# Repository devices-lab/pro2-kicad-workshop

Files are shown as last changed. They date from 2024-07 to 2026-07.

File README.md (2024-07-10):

# PCB design walkthrough with KiCad workshop

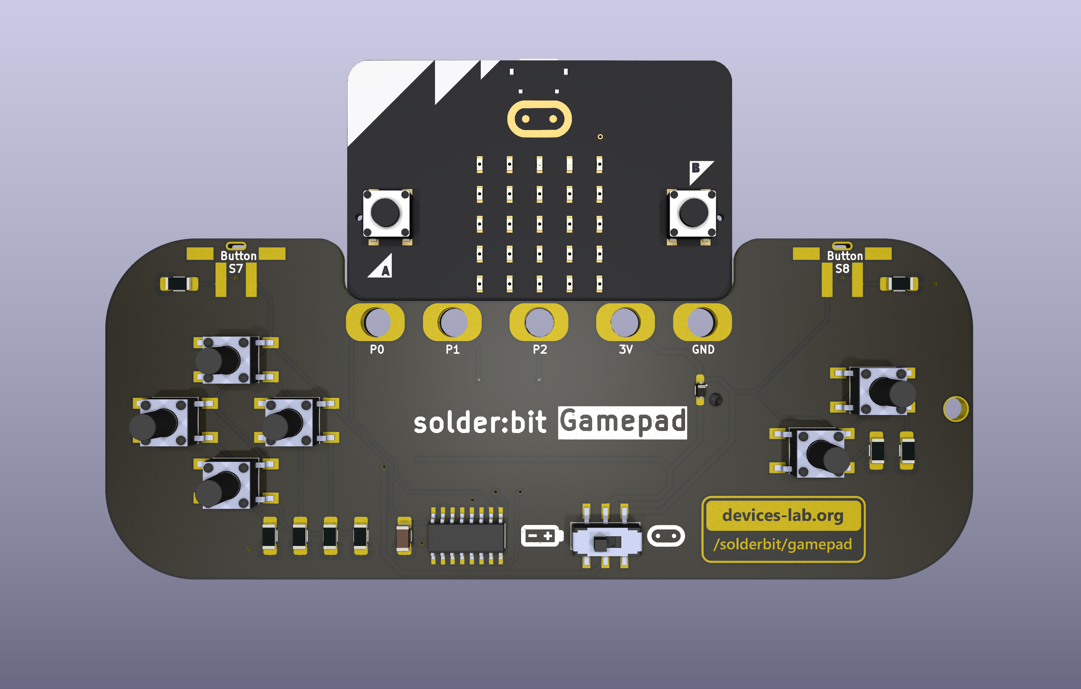
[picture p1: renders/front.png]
Front render of the solder:bit Gamepad PCB A render of the solder:bit Gamepad version of the board


## Tasks

You are given the task of extending the solder:bit Gamepad boards with more NeoPixels. A design review has highlighted that we need more blinking lights than the 5x5 LED matrix on the micro:bit can supply!

1. Download the existing design files by cloning this repository.
2. Get familiar with the NeoPixel (WS2812B) datasheet and the exisiting schematic for version 0.5.
3. Open up KiCad, and begin with the Schematic Editor - adding symbols, assiginging footprints, adding values, etc.
4. Move onto the PCB Editor and import the changes from the schematic - moving footprints, routing, zone filling, DRC, etc.
5. Build a bill of materials (BOM) and a set of Gerber fabrication files for the next workshop!
6. Use Git for version control of your KiCad project.

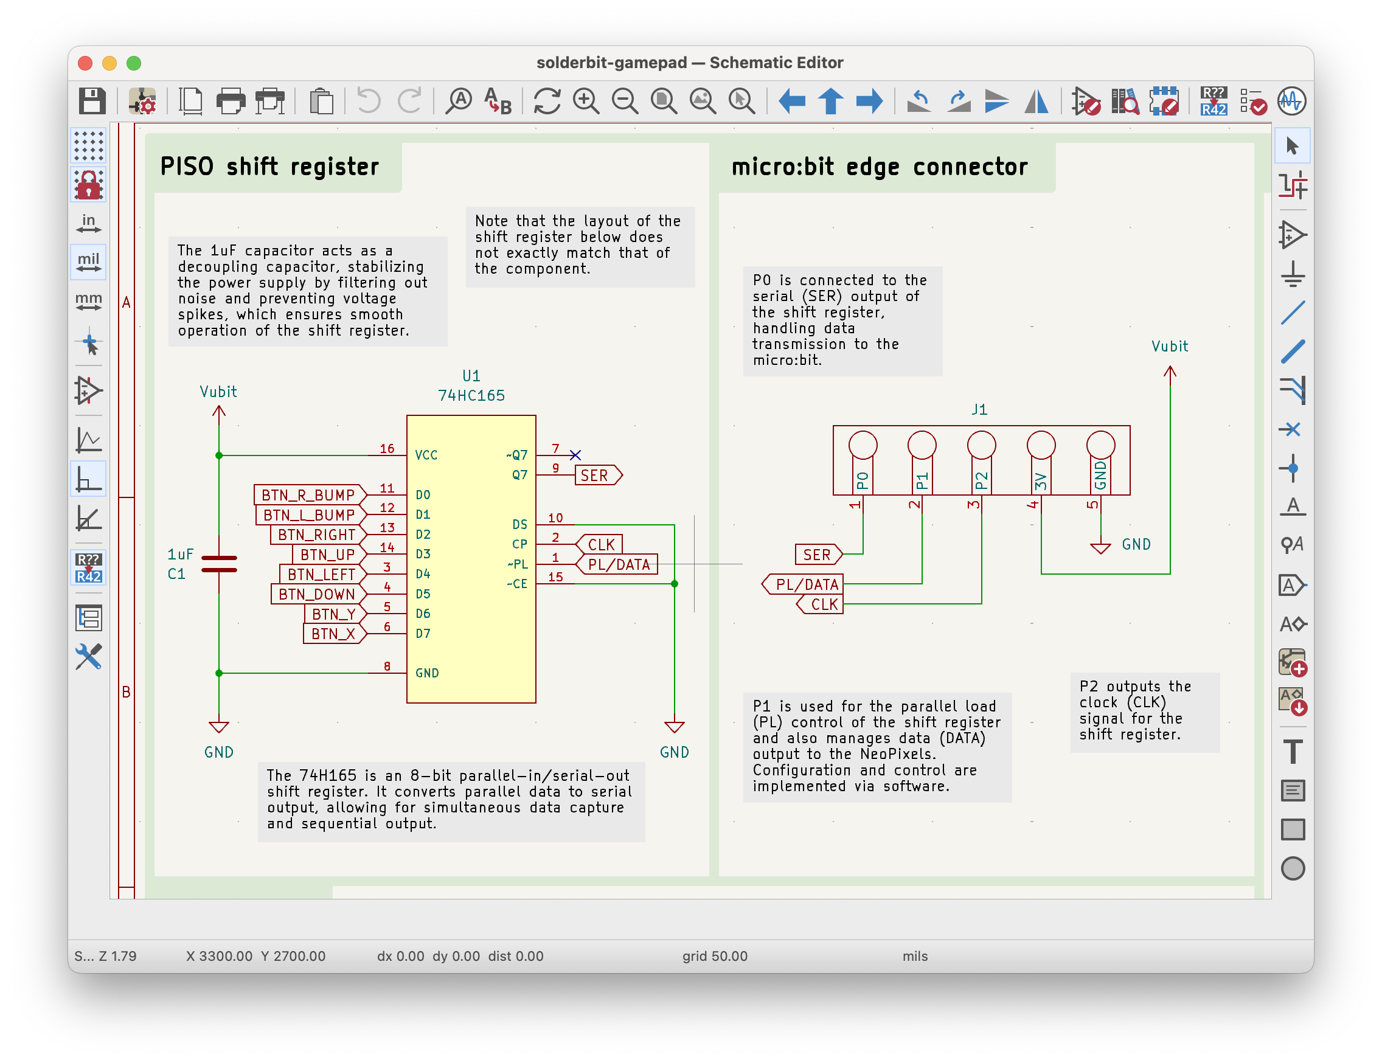
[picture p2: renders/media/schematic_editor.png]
KiCad 8.0 Schematic Editor preview

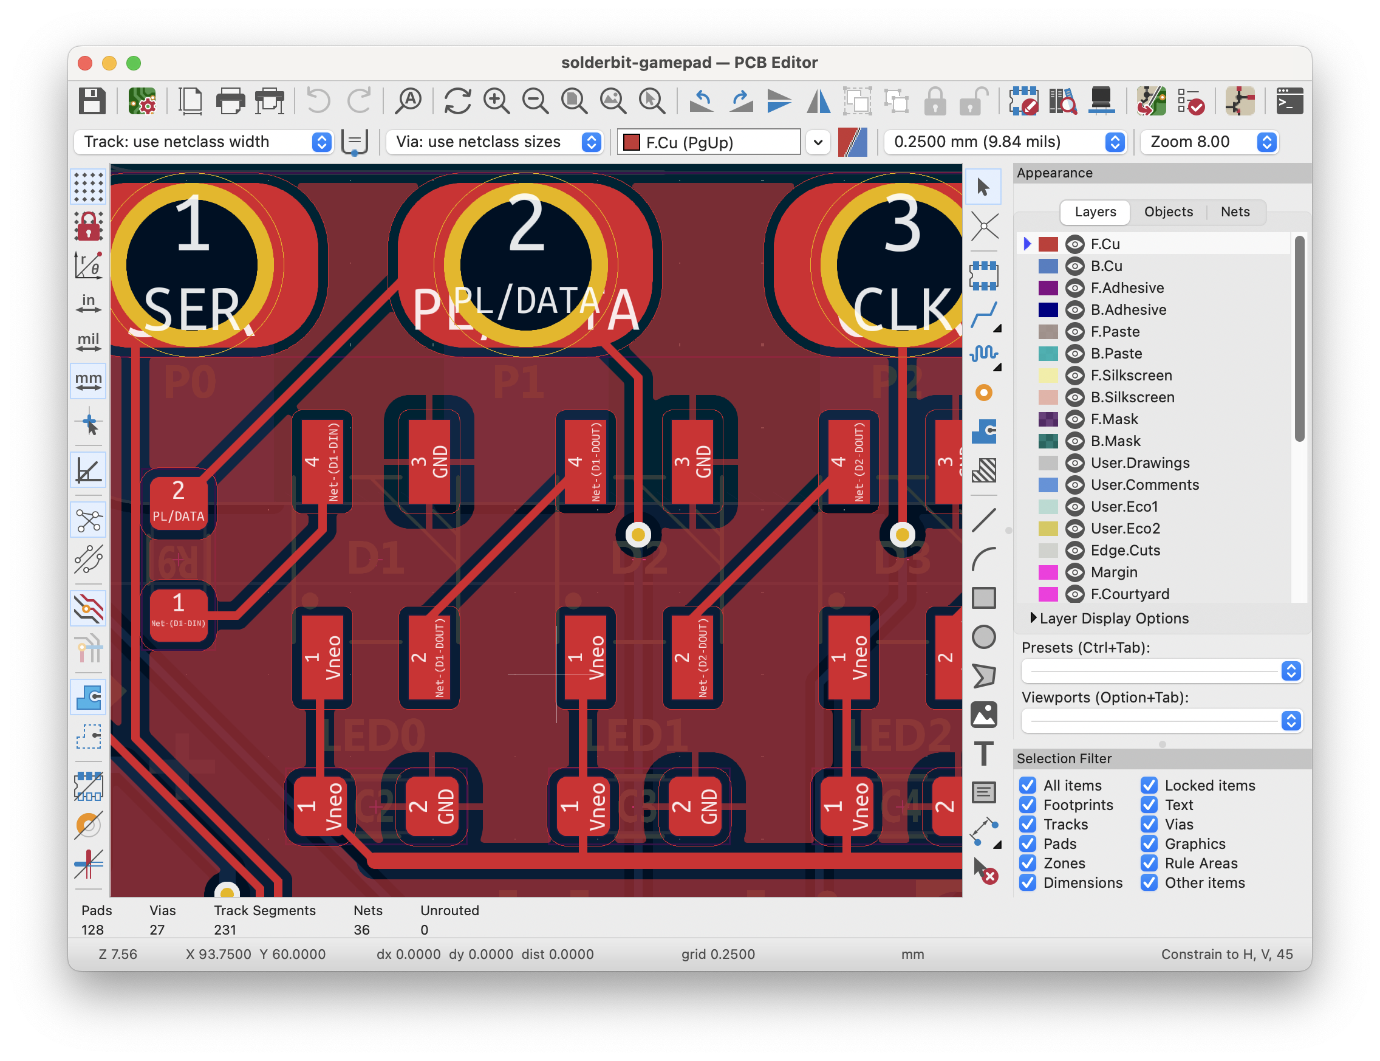
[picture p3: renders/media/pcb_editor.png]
KiCad 8.0 PCB Editor preview


Don’t worry if you don’t manage to get all the steps here completed, as we also supply a set of completed production files (BOM and Gerber files) in the same repository which can be used for the next session.

## Handy web links

- [solder:bit Gamepad repository](https://github.com/devices-lab/solderbit-gamepad)
- [KiCad 8.0 documentation](https://docs.kicad.org/8.0/en/)
- [Git cheat sheet](https://education.github.com/git-cheat-sheet-education.pdf)

## Credits

Thanks to [Dr John Vidler](https://github.com/JohnVidler) and [Aron Eggens](https://github.com/mac-aron), the Computing and Communications departement at Lancaster University, and everyone at the [Devices Lab](https://github.com/devices-lab).

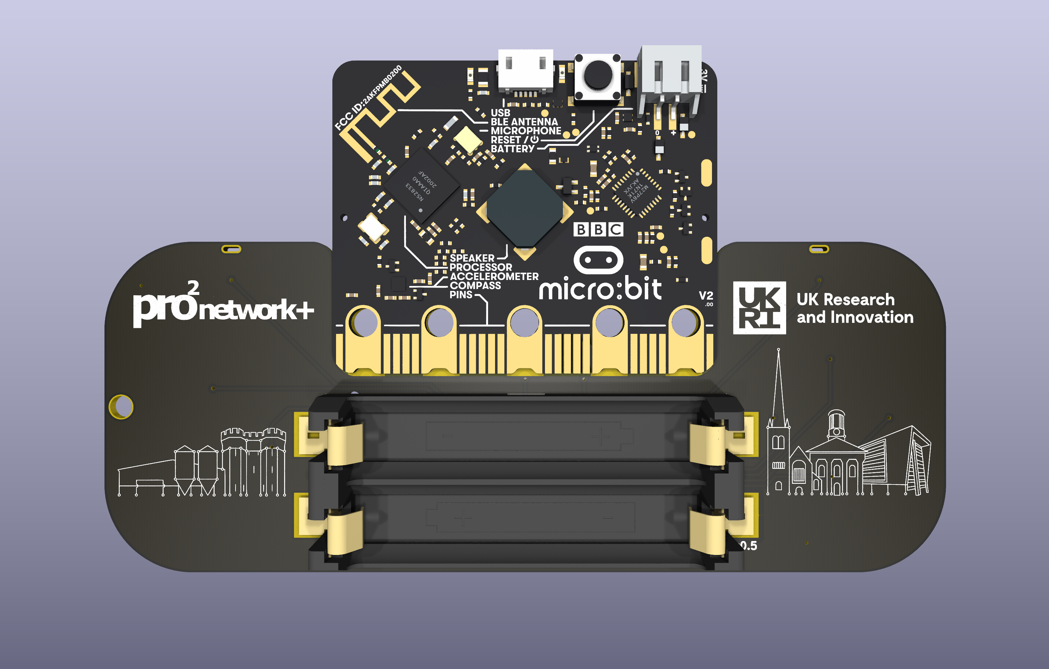
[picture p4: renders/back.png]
Rear render of the solder:bit Gamepad A render of the solder:bit Gamepad version of the board


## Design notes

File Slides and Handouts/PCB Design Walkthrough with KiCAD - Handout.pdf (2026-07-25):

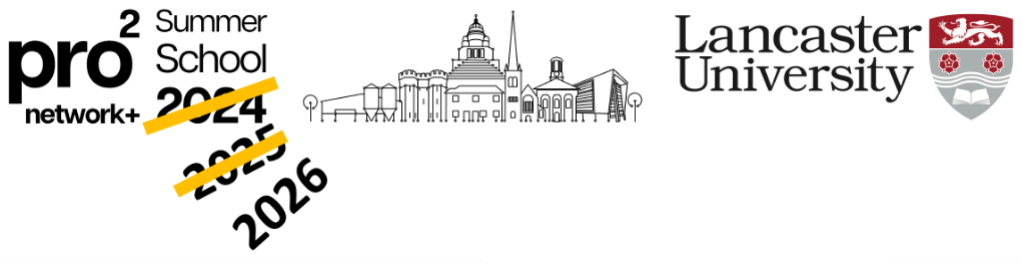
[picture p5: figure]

# PCB Design Walkthrough with KiCAD

John Vidler and Aron Eggens Computing and Communications Lancaster University

# https://tinyurl.com/kicad-class

You are given the task of extending the Solder:bit boards with more NeoPixel LEDs. A design review has highlighted that we need more blinking lights than the 5x5 LED matrix on the Micro:bit can supply!

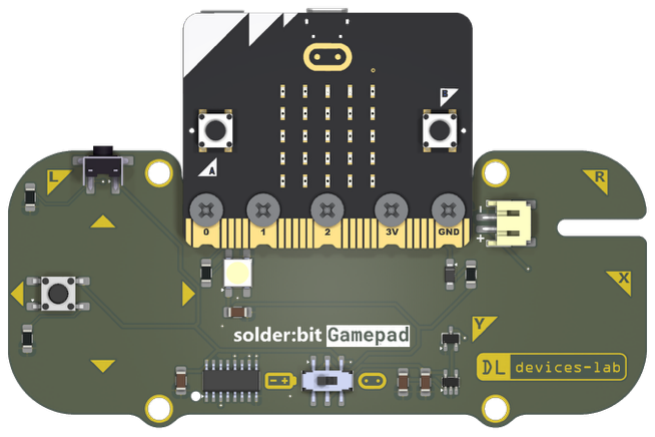
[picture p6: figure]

1. Download the existing design files by cloning or downloading the repository

https://github.com/devices-lab/pro2-kicad-workshop

( Direct Zip download: https://tinyurl.com/kicad-files )

2. Add 5 Neopixels and their support components to the design in the Schematic Editor
3. Select which footprints you need for the new parts with the Part Selection tool
4. Move to the PCB Layout Editor and import the changes
5. Lay out your new components (extra points for being artistic with your placement! 😊)
6. Build a Bill Of Materials (BOM) and Gerber file set for the next workshop

## Online KiCAD documentation https://docs.kicad.org/

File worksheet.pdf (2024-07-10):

## PCB Design Walkthrough with KiCAD

John Vidler and Aron Eggens Computing and Communications Lancaster University
https://github.com/devices-lab/pro2-kicad-workshop

You are given the task of extending the Solder:bit boards with more NeoPixel LEDs. A design review has highlighted that we need more blinking lights than the 5x5 LED matrix on the Micro:bit can supply!

## Tasks:

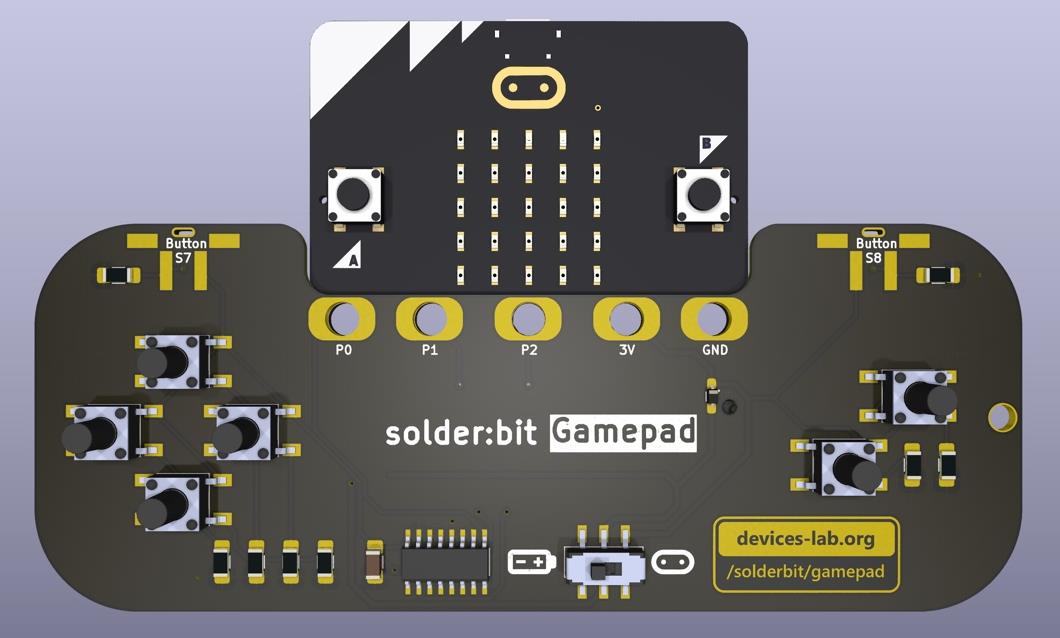
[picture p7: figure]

1. Download the existing design files by cloning the Git repository:

https://github.com/devices-lab/pro2-kicad-workshop

2. Add 5 Neopixels and their support components to the design in the Schematic Editor
3. Select which footprints you need for the new parts with the Part Selection tool
4. Move to the PCB Layout Editor and import the changes
5. Lay out your new components (extra points for being artistic with your placement! )
6. Build a Bill Of Materials (BOM) and Gerber file set for the next workshop

Don’t worry if you don’t manage to get all the steps here completed, as we also supply a set of completed production files (BOM and Gerber files) in the same repository which can be used for the next session.

## Handy Web Links:

- https://docs.kicad.org/8.0/en/ - The Version 8 KiCAD documentation
- https://education.github.com/git-cheat-sheet-education.pdf - A Git cheat sheet

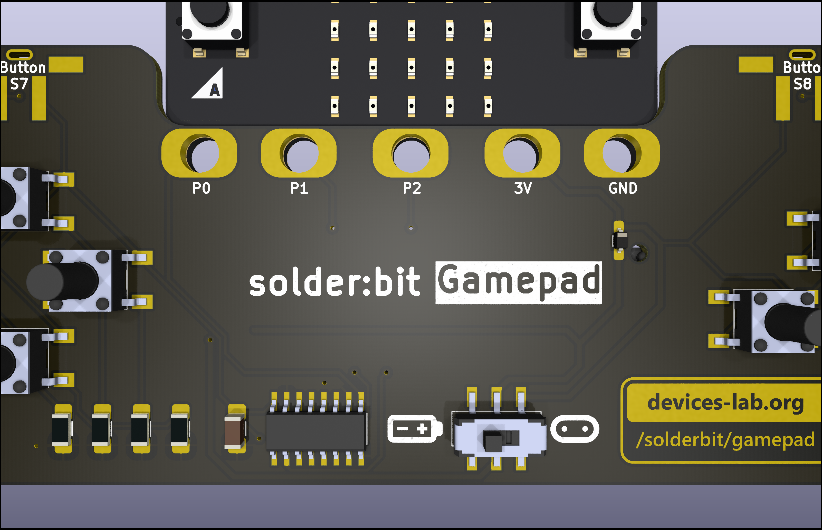
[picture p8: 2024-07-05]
renders/front-zoom.png

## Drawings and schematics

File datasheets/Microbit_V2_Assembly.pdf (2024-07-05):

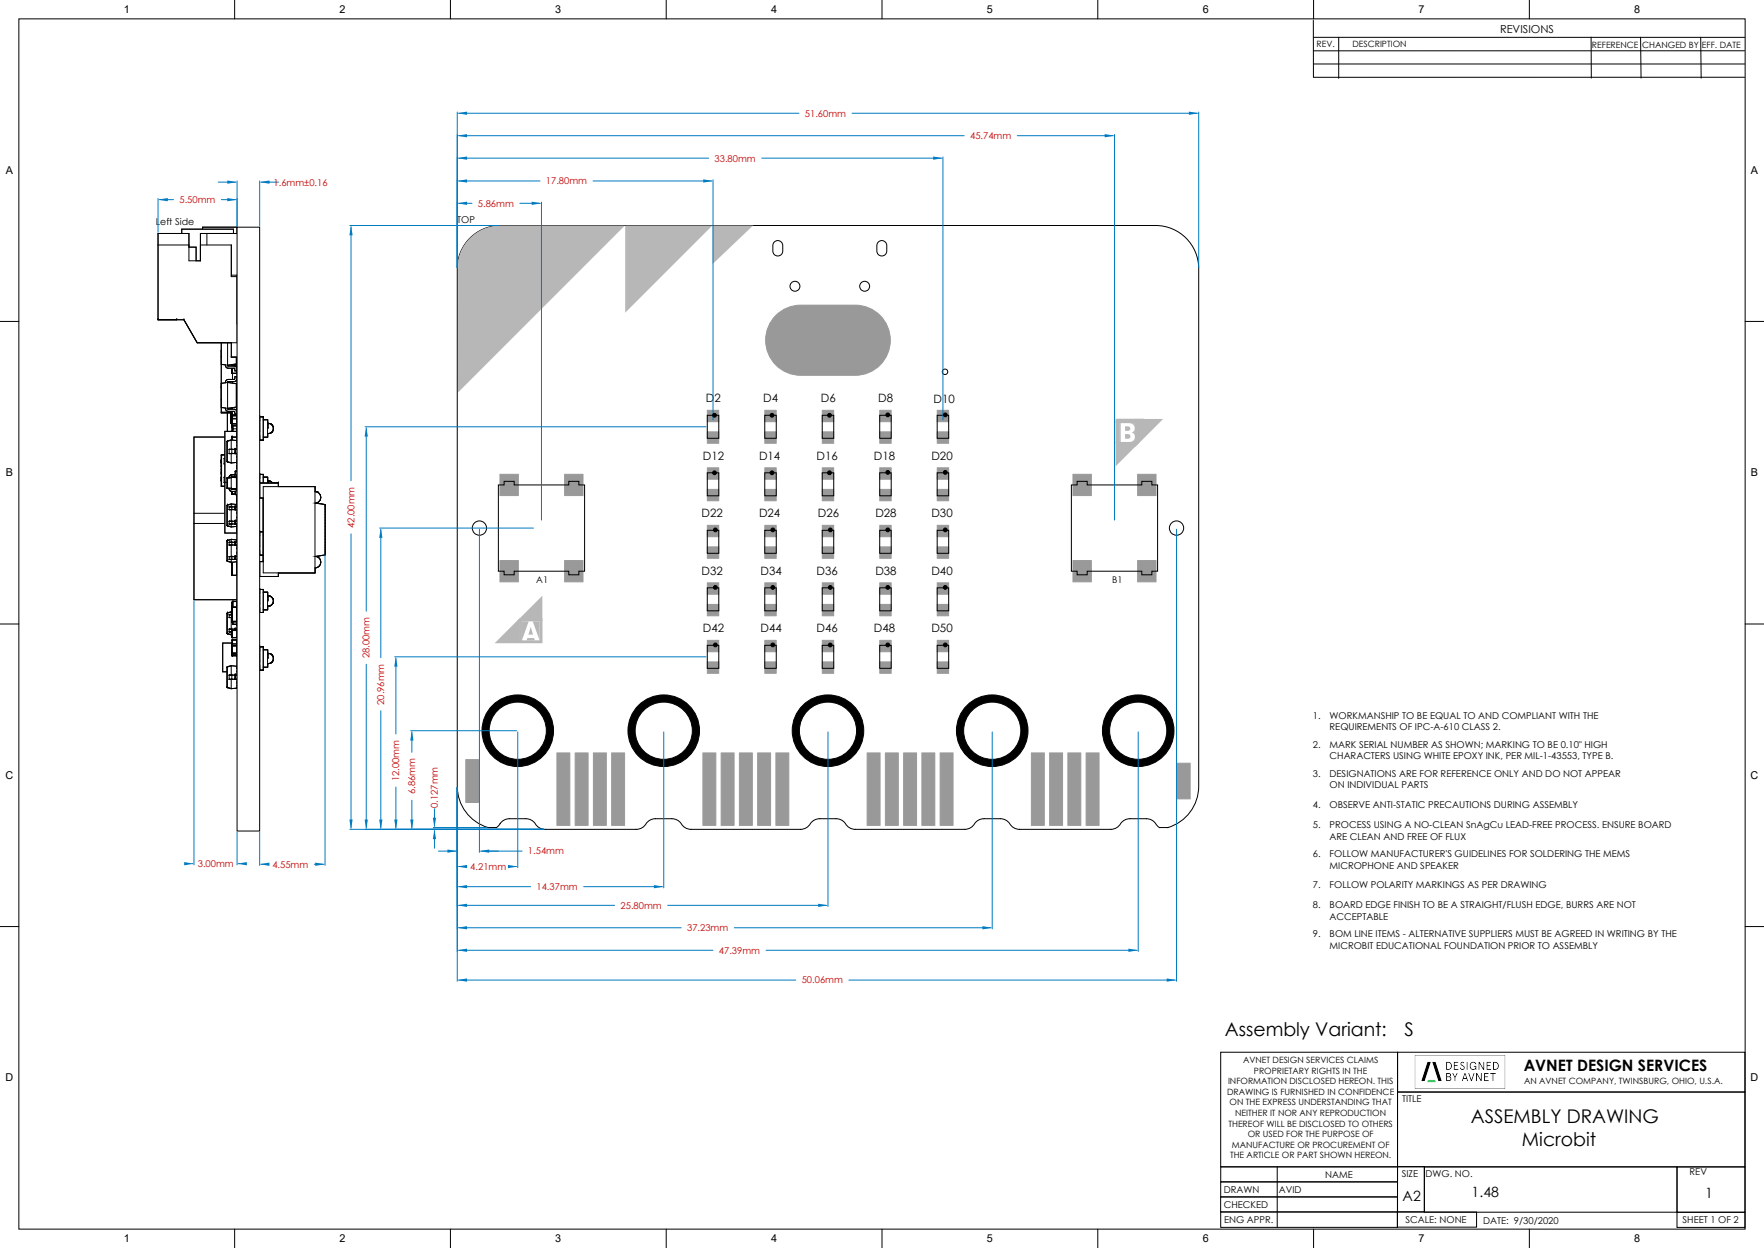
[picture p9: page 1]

WORKMANSHIP TO BE EQUAL TO AND COMPLIANT WITH THE
REQUIREMENTS OF IPC-A-610 CLASS 2.
MARK SERIAL NUMBER AS SHOWN; MARKING TO BE 0.10" HIGH
CHARACTERS USING WHITE EPOXY INK, PER MIL-1-43553, TYPE B.
DESIGNATIONS ARE FOR REFERENCE ONLY AND DO NOT APPEAR
ON INDIVIDUAL PARTS
4. OBSERVE ANTI-STATIC PRECAUTIONS DURING ASSEMBLY
PROCESS USING A NO-CLEAN SnAgCu LEAD-FREE PROCESS. ENSURE BOARD
ARE CLEAN AND FREE OF FLUX
FOLLOW MANUFACTURER'S GUIDELINES FOR SOLDERING THE MEMS
MICROPHONE AND SPEAKER
7. FOLLOW POLARITY MARKINGS AS PER DRAWING
BOARD EDGE FINISH TO BE A STRAIGHT/FLUSH EDGE, BURRS ARE NOT
ACCEPTABLE
BOM LINE ITEMS - ALTERNATIVE SUPPLIERS MUST BE AGREED IN WRITING BY THE
MICROBIT EDUCATIONAL FOUNDATION PRIOR TO ASSEMBLY

AVNET DESIGN SERVICES CLAIMS
PROPRIETARY RIGHTS IN THE
INFORMATION DISCLOSED HEREON. THIS
DRAWING IS FURNISHED IN CONFIDENCE
ON THE EXPRESS UNDERSTANDING THAT
NEITHER IT NOR ANY REPRODUCTION
THEREOF WILL BE DISCLOSED TO OTHERS
OR USED FOR THE PURPOSE OF
MANUFACTURE OR PROCUREMENT OF
THE ARTICLE OR PART SHOWN HEREON.

AVNET DESIGN SERVICES
AN AVNET COMPANY, TWINSBURG, OHIO, U.S.A.
ASSEMBLY DRAWING
Microbit

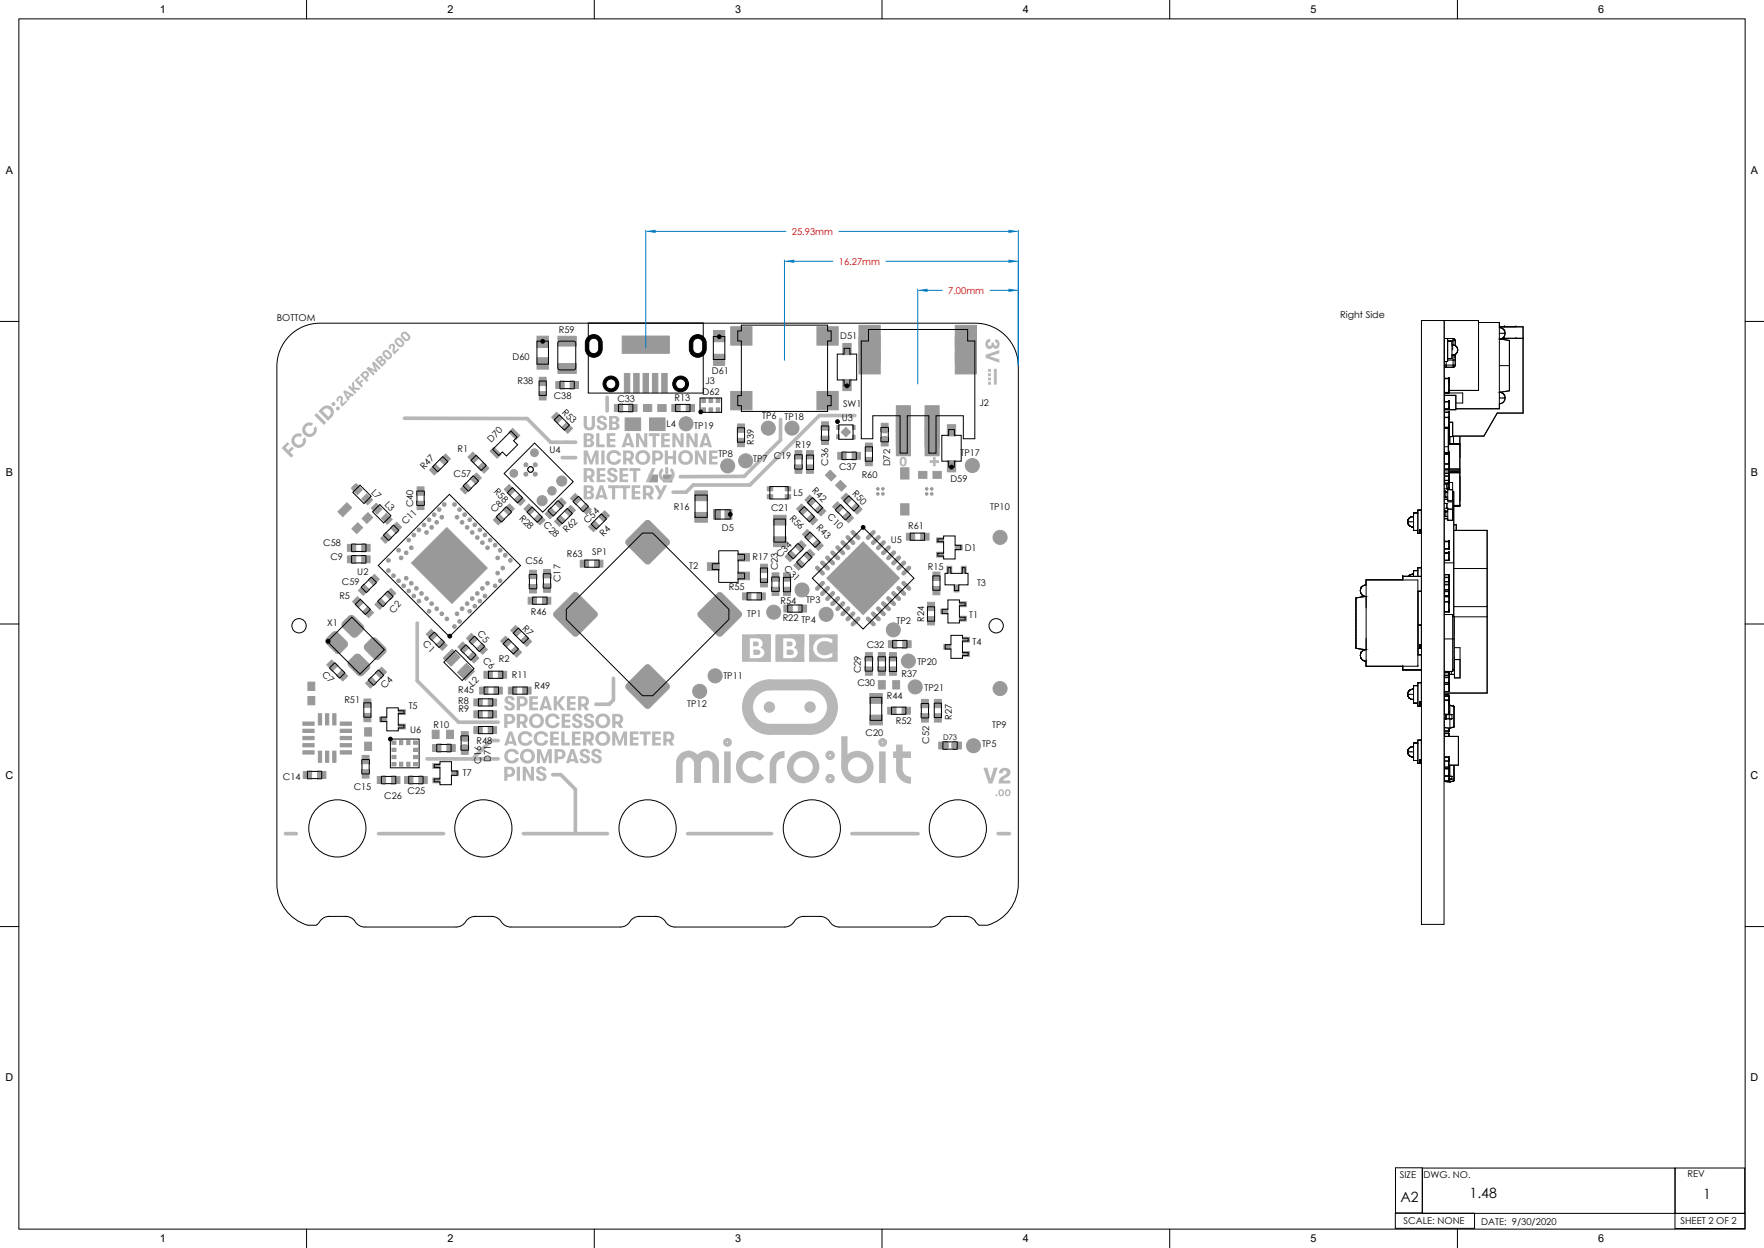
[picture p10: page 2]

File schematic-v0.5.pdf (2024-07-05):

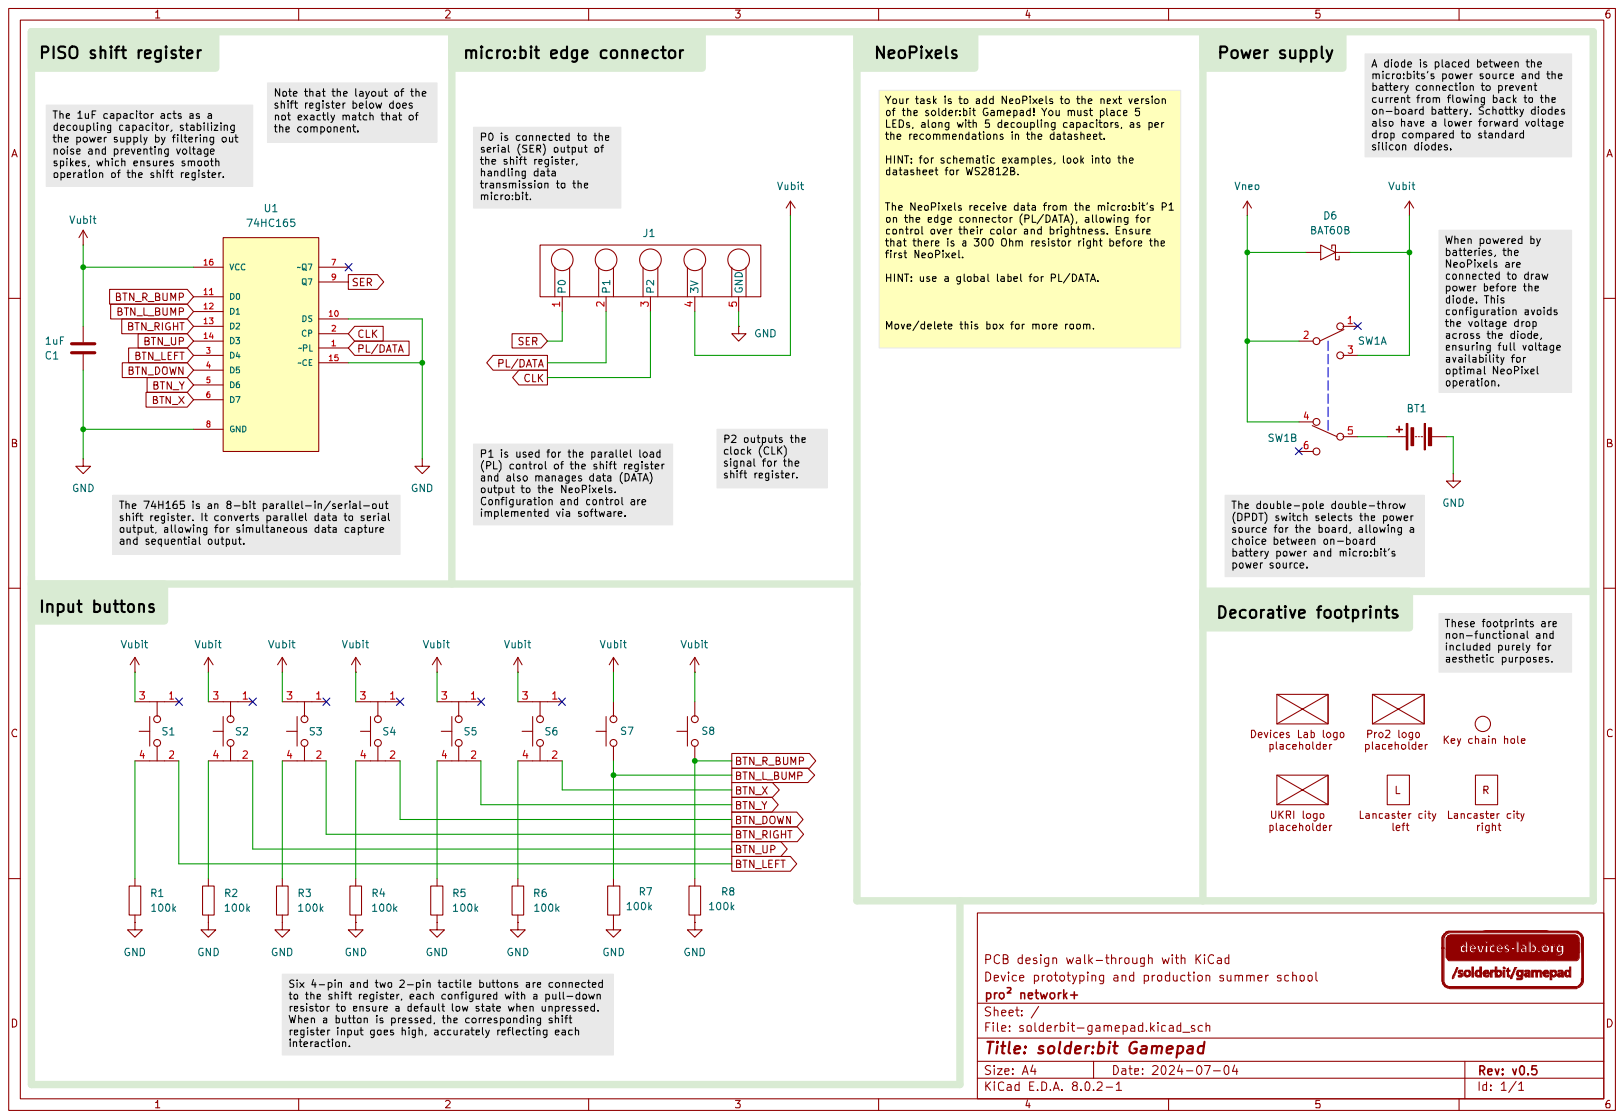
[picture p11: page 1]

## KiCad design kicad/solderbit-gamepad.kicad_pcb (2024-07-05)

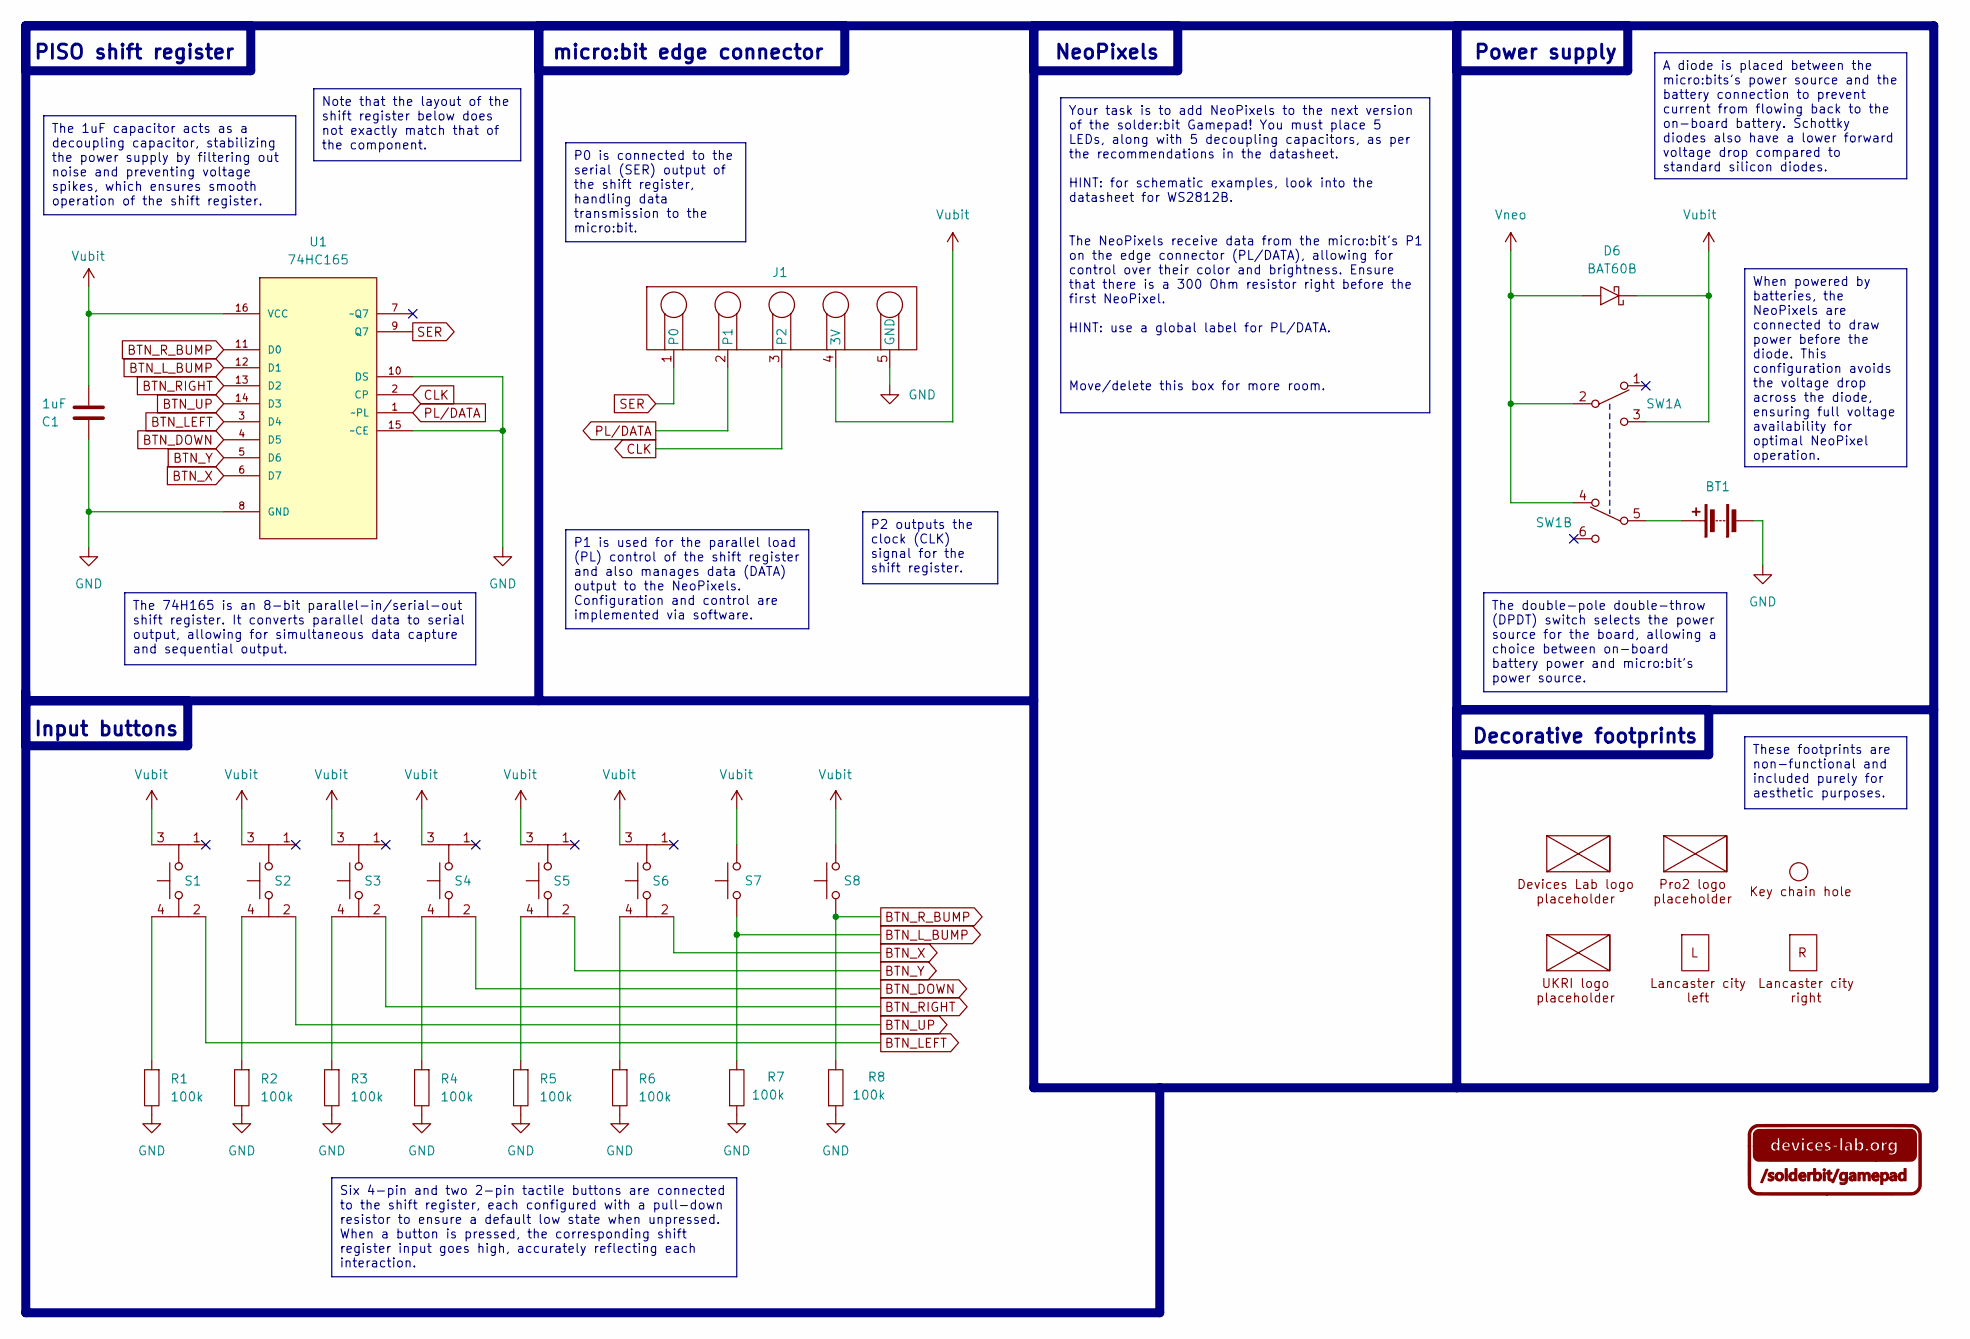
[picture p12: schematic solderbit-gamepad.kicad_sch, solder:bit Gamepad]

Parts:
BT1: BH-AAA-B5AA001; Battery_Holder
C1: 1uF; 1206_Capacitor
D6: BAT60B; Schottky_Diode_SOD-323
G1: Devices-Lab_Logo_H9mm
G2: Pro2_Logo
G3: Key_Chain_Hole
G4: UKRI_Logo
G5: LSS_L
G6: LSS_R
J1: Microbit; Microbit_Edge_Connector
R1, R2, R3, R4, R5, R6, R7, R8: 100k; 1206_Resistor
S1, S2, S3, S4, S5, S6: TS-1002S-AR06026; Tactile_Switch
S7: TS-1037-A4B3-D2; Tactile_Switch_Left_90_Degrees
S8: TS-1037-A4B3-D2; Tactile_Switch_Right_90_Degrees
SW1: MST22D18G2 125; Sliding_Switch_DPDT
U1: 74HC165; Shift_Register_74HC165D

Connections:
BTN_DOWN: S4.2, U1.4 (D5)
BTN_LEFT: S1.2, U1.3 (D4)
BTN_L_BUMP: R7.2, S7.2, U1.12 (D1)
BTN_RIGHT: S3.2, U1.13 (D2)
BTN_R_BUMP: R8.2, S8.2, U1.11 (D0)
BTN_UP: S2.2, U1.14 (D3)
BTN_X: S6.2, U1.6 (D7)
BTN_Y: S5.2, U1.5 (D6)
CLK: J1.3 (P2), U1.2 (CP)
GND: BT1.2 (-), C1.1, J1.5 (GND), R1.2, R2.2, R3.2, R4.2, R5.2, R6.2, R7.1, R8.1, U1.8 (GND), U1.10 (DS), U1.15 (~CE)
unnamed: BT1.1 (+), SW1.5 (B)
unnamed: R1.1, S1.4
unnamed: R2.1, S2.4
unnamed: R3.1, S3.4
unnamed: R4.1, S4.4
unnamed: R5.1, S5.4
unnamed: R6.1, S6.4
PL/DATA: J1.2 (P1), U1.1 (~PL)
SER: J1.1 (P0), U1.9 (Q7)
Vneo: D6.2 (A), SW1.2 (B), SW1.4 (A)
Vubit: C1.2, D6.1 (K), J1.4 (3V), S1.3, S2.3, S3.3, S4.3, S5.3, S6.3, S7.1, S8.1, SW1.3 (C), U1.16 (VCC)

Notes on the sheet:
P0 is connected to the serial (SER) output of the shift register, handling data transmission to the micro:bit.
When powered by batteries, the NeoPixels are connected to draw power before the diode. This configuration avoids the voltage drop across the diode, ensuring full voltage availability for optimal NeoPixel operation.
P2 outputs the clock (CLK) signal for the shift register.
P1 is used for the parallel load (PL) control of the shift register and also manages data (DATA) output to the NeoPixels. Configuration and control are implemented via software.
The 74H165 is an 8-bit parallel-in/serial-out shift register. It converts parallel data to serial output, allowing for simultaneous data capture and sequential output.
Your task is to add NeoPixels to the next version of the solder:bit Gamepad! You must place 5 LEDs, along with 5 decoupling capacitors, as per the recommendations in the datasheet. HINT: for schematic examples, look into the datasheet for WS2812B. The NeoPixels receive data from the micro:bit's P1 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
The double-pole double-throw (DPDT) switch selects the power source for the board, allowing a choice between on-board battery power and micro:bit's power source.
Six 4-pin and two 2-pin tactile buttons are connected to the shift register, each configured with a pull-down resistor to ensure a default low state when unpressed. When a button is pressed, the corresponding shift register input goes high, accurately reflecting each interaction.
These footprints are non-functional and included purely for aesthetic purposes.
A diode is placed between the micro:bits's power source and the battery connection to prevent current from flowing back to the on-board battery. Schottky diodes also have a lower forward voltage drop compared to standard silicon diodes.
The 1uF capacitor acts as a decoupling capacitor, stabilizing the power supply by filtering out noise and preventing voltage spikes, which ensures smooth operation of the shift register.
Note that the layout of the shift register below does not exactly match that of the component.
NeoPixels
Input buttons
Power supply
micro:bit edge connector
Decorative footprints
PISO shift register

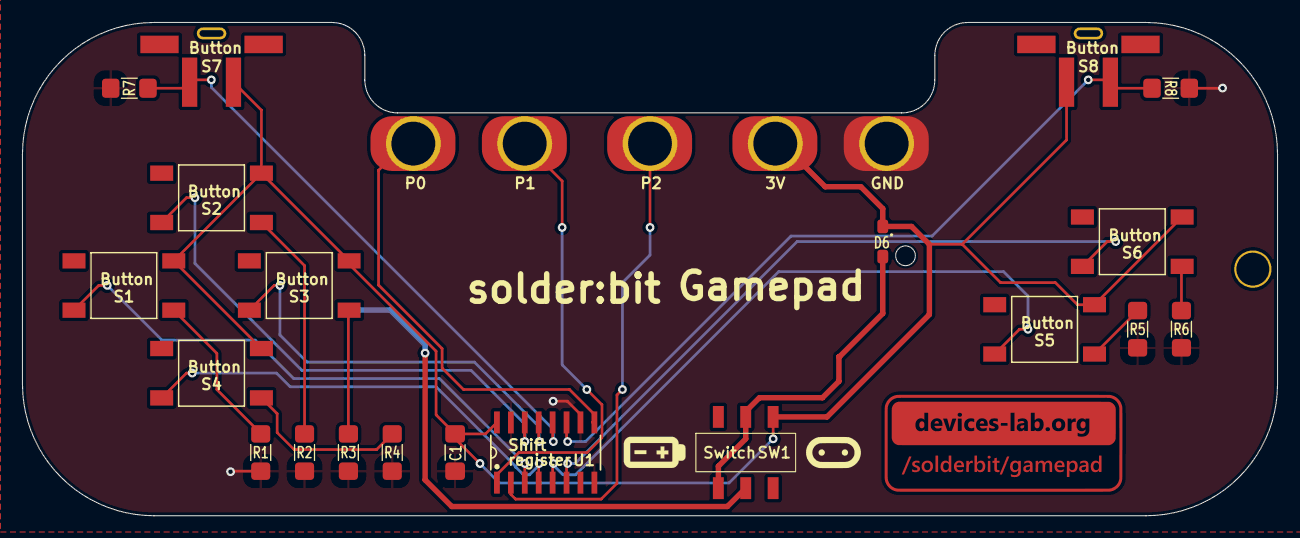
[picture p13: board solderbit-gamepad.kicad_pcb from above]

Board: 2 copper layers, 114.5 x 45.0 mm, 28 parts (0 on the bottom side), 21 nets.

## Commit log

2024-07-03 Added KiCad files based on v0.6
    [solderbit-gamepad.kicad_pcb, solderbit-gamepad.kicad_sch]
2024-07-05 KiCad font fixes and 3D renders
    [solderbit-gamepad-B_Cu.gbl, solderbit-gamepad-B_Mask.gbs, solderbit-gamepad-B_Paste.gbp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]
2024-07-05 Updated gitignore, removed spurious DS_Store and removed neopixel busbar
    [solderbit-gamepad.kicad_pcb]
2024-07-05 FONT fixes
    [solderbit-gamepad.kicad_pcb]
